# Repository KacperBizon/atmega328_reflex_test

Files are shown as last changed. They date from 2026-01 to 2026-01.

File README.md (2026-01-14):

# reflex test
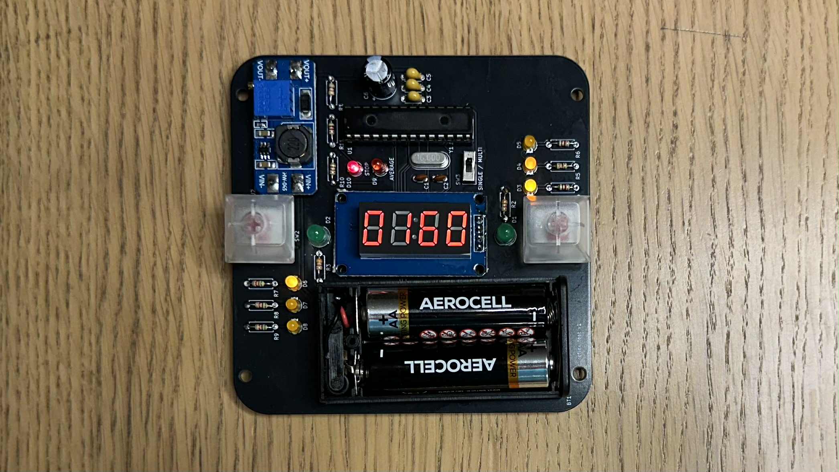
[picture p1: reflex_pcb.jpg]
pcb image


### How to use
- You win by pressing the button on your side faster than your opponent
- To go to the next round press any button for 1s
- Singleplayer - the game finishes with first keypress, multiplayer - both players need to press the keys to finish round 
### Components
- R1 - 10K
- R2-R11 - recommended 3.3k-6.8k
- C1,C2 - 22pF
- C3,C4,C5 - 100nF
- C6 - 10uF

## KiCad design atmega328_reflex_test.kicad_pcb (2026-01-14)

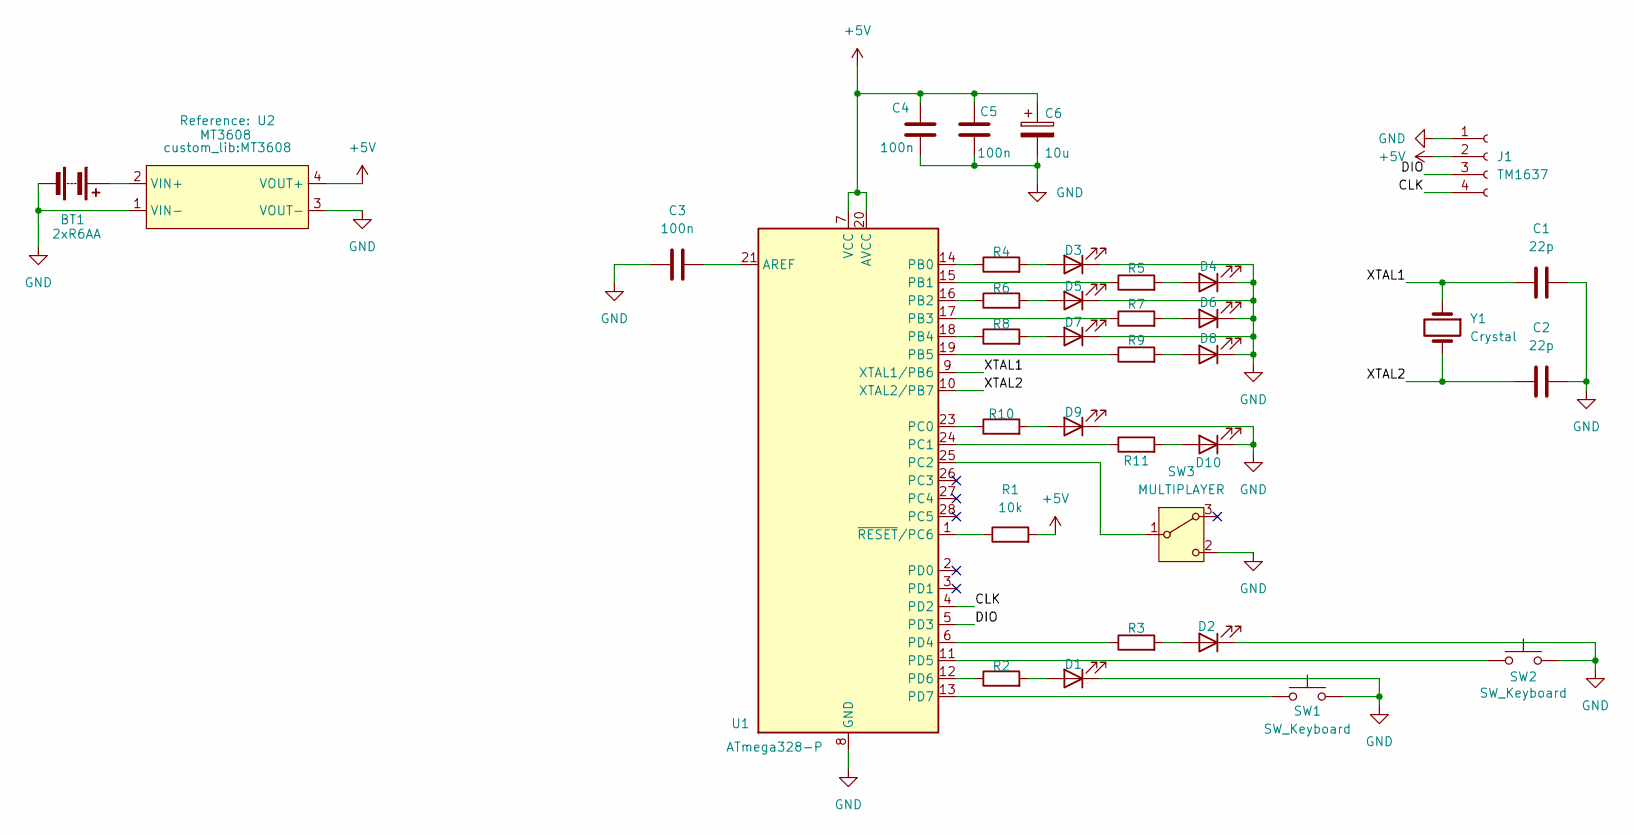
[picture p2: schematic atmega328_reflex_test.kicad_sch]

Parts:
BT1: 2xR6AA; 2xAA_holder
C1, C2: 22p; C_Disc_D3.0mm_W1.6mm_P2.50mm
C3, C4, C5: 100n; C_Disc_D4.3mm_W1.9mm_P5.00mm
C6: 10u; CP_Radial_D8.0mm_P3.80mm
D1, D2: LED; LED_D5.0mm
D3, D4, D5, D6, D7, D8, D9, D10: LED; LED_D3.0mm
J1: TM1637; HW069
R1: 10k; R_Axial_DIN0207_L6.3mm_D2.5mm_P7.62mm_Horizontal
R2, R3: 3k3; R_Axial_DIN0207_L6.3mm_D2.5mm_P7.62mm_Horizontal
R4, R5, R6, R7, R8, R9, R10, R11: 5k1; R_Axial_DIN0207_L6.3mm_D2.5mm_P7.62mm_Horizontal
SW1, SW2: SW_Keyboard; SW_Cherry_MX_1.00u_PCB
SW3: MULTIPLAYER; SW_Slide_8.6x3.8x7.0_P2.54mm
U1: ATmega328-P; DIP-28_W7.62mm
U2: MT3608
Y1: Crystal; Crystal_HC49-4H_Vertical

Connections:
+5V: C4.2, C5.2, C6.1, J1.2, R1.2, U1.7 (VCC), U1.20 (AVCC), U2.4 (VOUT+)
/CLK: J1.4, U1.4 (PD2)
/DIO: J1.3, U1.5 (PD3)
/XTAL1: C1.1, U1.9 (XTAL1/PB6), Y1.1
/XTAL2: C2.1, U1.10 (XTAL2/PB7), Y1.2
GND: BT1.2 (-), C1.2, C2.2, C3.1, C4.1, C5.1, C6.2, D1.1 (K), D2.1 (K), D3.1 (K), D4.1 (K), D5.1 (K), D6.1 (K), D7.1 (K), D8.1 (K), D9.1 (K), D10.1 (K), J1.1, SW1.2, SW2.2, SW3.2 (C), U1.8 (GND), U1.22 (GND), U2.1 (VIN-), U2.3 (VOUT-)
unnamed: BT1.1 (+), U2.2 (VIN+)
unnamed: D1.2 (A), R2.2
unnamed: D2.2 (A), R3.2
unnamed: D3.2 (A), R4.2
unnamed: D4.2 (A), R5.2
unnamed: D5.2 (A), R6.2
unnamed: D6.2 (A), R7.2
unnamed: D7.2 (A), R8.2
unnamed: D8.2 (A), R9.2
unnamed: D9.2 (A), R10.2
unnamed: D10.2 (A), R11.2
unnamed: SW3.1 (B), U1.25 (PC2)
unnamed: C3.2, U1.21 (AREF)
unnamed: R4.1, U1.14 (PB0)
unnamed: R5.1, U1.15 (PB1)
unnamed: R6.1, U1.16 (PB2)
unnamed: R7.1, U1.17 (PB3)
unnamed: R8.1, U1.18 (PB4)
unnamed: R9.1, U1.19 (PB5)
unnamed: R10.1, U1.23 (PC0)
unnamed: R11.1, U1.24 (PC1)
unnamed: R3.1, U1.6 (PD4)
unnamed: SW2.1, U1.11 (PD5)
unnamed: R2.1, U1.12 (PD6)
unnamed: SW1.1, U1.13 (PD7)
unnamed: R1.1, U1.1 (~RESET/PC6)

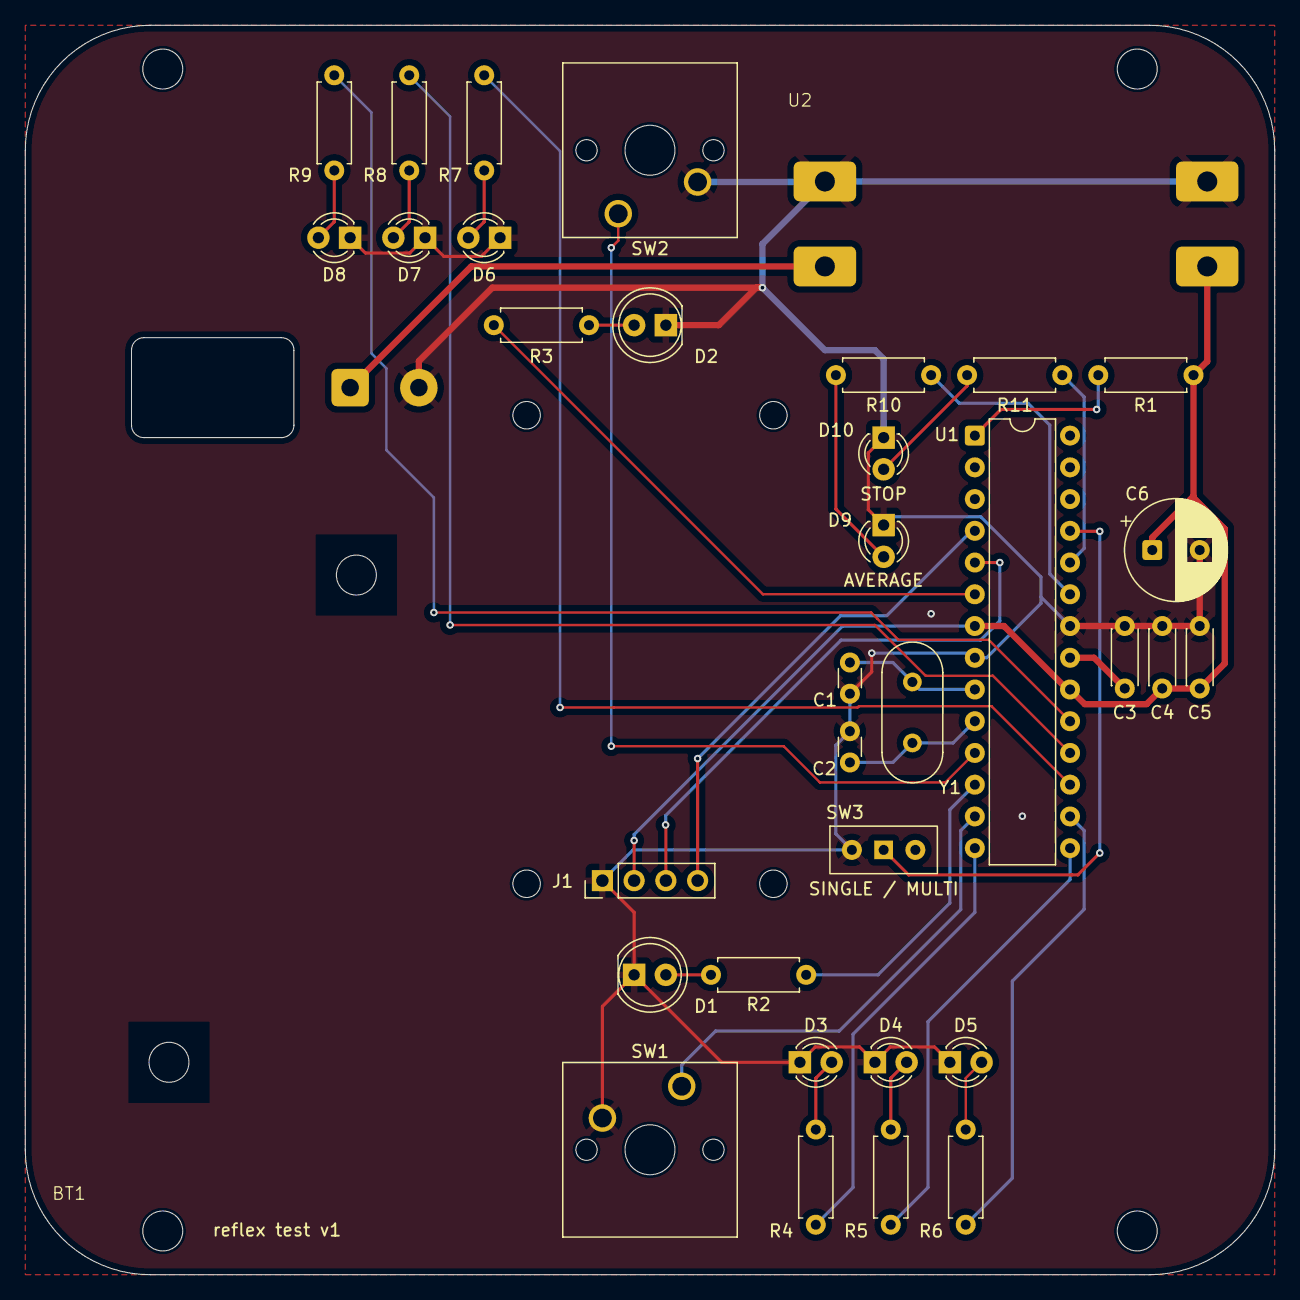
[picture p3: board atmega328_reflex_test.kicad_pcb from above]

Board: 2 copper layers, 100.0 x 100.0 mm, 39 parts (0 on the bottom side), 32 nets.

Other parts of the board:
MH1, MH2, MH3, MH4: MountingHole_3.2mm_M3_DIN965

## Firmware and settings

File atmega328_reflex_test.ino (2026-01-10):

#include <TM1637Display.h>
#include <SPI.h>
#include <SD.h>
#include <math.h>

#define CLK 2
#define DIO 3
TM1637Display display(CLK, DIO);
uint8_t data[] = {0xff, 0xff, 0xff, 0xff};

const byte led_p2 = 4;                    //player 2 main LED
const byte switch_p2 = 5;                 //player 2 switch
const byte led_p1 = 6;                    //player 1 main LED
const byte switch_p1 = 7;                 //player 1 switch

const byte led_score_p1[] = {8, 9, 10};   //player 1 score LEDs
const byte led_score_p2[] = {11, 12, 13}; //player 2 score LEDs

const byte led_avg =  14;                 //avg score LED
const byte led_stop = 15;                 //game stop LED
const byte multiplayer_switch = 16;       //multiplayer if HIGH

const byte MAX_SCORE = 3;
const byte blink_count = 5;               //initial blinks
const int timebetween = 1000;             //time between games

byte multiplayer = 1;
unsigned long p1Total = 0;
unsigned long p2Total = 0;
byte scoreP1 = 0;
byte scoreP2 = 0;

void active_delay(int time)
{
  digitalWrite(led_stop, HIGH);
  while (time)
  {
    if ((digitalRead(switch_p1) == LOW) || (digitalRead(switch_p2) == LOW))
    {
      delay(1);
      time--;
    }
  }
  digitalWrite(led_stop, LOW);
}

void blinkMainLEDs()
{
  for (int i = 0; i < blink_count; i++)
  {
    digitalWrite(led_p1, HIGH);
    digitalWrite(led_p2, HIGH);
    delay(300);

    digitalWrite(led_p1, LOW);
    digitalWrite(led_p2, LOW);
    delay(300);
  }
}

void updateDisplay(unsigned long value, int scoreP1, int scoreP2)
{
  for (int i = 0; i < MAX_SCORE; i++)
  {
    digitalWrite(led_score_p1[i], LOW);
    digitalWrite(led_score_p2[i], LOW);
  }

  for (int i = 0; i < scoreP1; i++)
  {
    digitalWrite(led_score_p1[i], HIGH);
  }

  for (int i = 0; i < scoreP2; i++)
  {
    digitalWrite(led_score_p2[i], HIGH);
  }

  if(value == 0)
  {
    display.clear();
    return;
  }

  value /= 1000;
  
  data[3] = display.encodeDigit(value % 10);
  value /= 10;
  data[2] = display.encodeDigit(value % 10);
  value /= 10;
  data[1] = display.encodeDigit(value % 10);
  value /= 10;
  data[0] = display.encodeDigit(value % 10);

  display.setBrightness(0x01);
  display.setSegments(data);
}

void displayAverage(unsigned long p1Total, unsigned long p2Total, byte scoreP1, byte scoreP2)
{
  digitalWrite(led_avg, HIGH);

  if(multiplayer == 1)
  {
    //p1 average
    if(p1Total > 0)
    {
      digitalWrite(led_p1, HIGH);
      digitalWrite(led_p2, LOW);
      updateDisplay(p1Total/(scoreP1 + scoreP2), scoreP1, scoreP2);

      active_delay(timebetween);
    }

    //p2 average
    if(p2Total > 0)
    {
      digitalWrite(led_p1, LOW);
      digitalWrite(led_p2, HIGH);
      updateDisplay(p2Total/(scoreP1 + scoreP2), scoreP1, scoreP2);

      active_delay(timebetween);
    }
  }
  else //singleplayer
  {
    //p1 average
    if(p1Total > 0)
    {
      digitalWrite(led_p1, HIGH);
      digitalWrite(led_p2, LOW);
      updateDisplay(p1Total/(scoreP1), scoreP1, scoreP2);

      active_delay(timebetween);
    }

    //p2 average
    if(p2Total > 0)
    {
      digitalWrite(led_p1, LOW);
      digitalWrite(led_p2, HIGH);
      updateDisplay(p2Total/(scoreP2), scoreP1, scoreP2);

      active_delay(timebetween);
    }
  }

  digitalWrite(led_avg, LOW);
}

bool falseStart()
{
  unsigned long waitTime = random(3200, 7600) * 1000UL;
  unsigned long safeZone = 1000000UL;
  unsigned long startTime = micros();

  while (micros() - startTime < waitTime)
  {
    if (micros() - startTime > safeZone)
    {
      if ((digitalRead(switch_p1) == LOW) || (digitalRead(switch_p2) == LOW))
      {
        data[3] = display.encodeDigit(15);
        data[2] = display.encodeDigit(15);
        data[1] = display.encodeDigit(15);
        data[0] = display.encodeDigit(15);
        display.setBrightness(0x01);
        display.setSegments(data);

        digitalWrite(led_stop, HIGH);

        active_delay(timebetween);
        return 1;
      }
    }
  }

  return 0;
}

void reflexTest()
{
  bool finished_players[2]={0, 0};
  digitalWrite(led_p1, HIGH);
  digitalWrite(led_p2, HIGH);

  unsigned long startTime = micros();
  unsigned long reactionTime = 0;

  while(finished_players[0] == 0 || finished_players[1] == 0)
  {
    //calculate time after falsestart()
    reactionTime = micros() - startTime;

    //player 1
    if (digitalRead(switch_p1) == LOW && finished_players[0] == 0)
    {
      if(finished_players[1] == 0)
      {
        digitalWrite(led_p1, HIGH);
        digitalWrite(led_p2, LOW);
        scoreP1++;
        updateDisplay(reactionTime, scoreP1, scoreP2);
      }

      p1Total += reactionTime;
      finished_players[0] = 1;

      if(multiplayer == 0)
        return;
    }

    //player 2
    if (digitalRead(switch_p2) == LOW && finished_players[1] == 0)
    {
      if(finished_players[0] == 0)
      {
        digitalWrite(led_p1, LOW);
        digitalWrite(led_p2, HIGH);
        scoreP2++;
        updateDisplay(reactionTime, scoreP1, scoreP2);
      }

      p2Total += reactionTime;
      finished_players[1] = 1;

      if(multiplayer == 0)
        return;
    }

    if (reactionTime > 9990000)
    {
      digitalWrite(led_p1, LOW);
      digitalWrite(led_p2, LOW);

      //both players didnt finish - doesnt count 
      if((finished_players[0] == 0) && (finished_players[1] == 0))
      {
        updateDisplay(9999000, scoreP1, scoreP2);
        return;
      }

      if(finished_players[0] == 0)
        p1Total += reactionTime;

      if(finished_players[1] == 0)
        p2Total += reactionTime;

      return;
    }
  }
}

void handleGame()
{
  display.clear();
  digitalWrite(led_p1, LOW);
  digitalWrite(led_p2, LOW);

  if (falseStart() == 0)
    reflexTest();

  active_delay(timebetween);
}

void setup() 
{
  randomSeed(analogRead(3));

  pinMode(switch_p1, INPUT_PULLUP);
  pinMode(switch_p2, INPUT_PULLUP);

  pinMode(led_p1, OUTPUT);
  pinMode(led_p2, OUTPUT);

  for (int i = 0; i < MAX_SCORE; i++) 
  {
    pinMode(led_score_p1[i], OUTPUT);
    pinMode(led_score_p2[i], OUTPUT);
  }

  pinMode(led_avg, OUTPUT);
  pinMode(led_stop, OUTPUT);
  pinMode(multiplayer_switch, INPUT_PULLUP);

  blinkMainLEDs();
}

void loop()
{
  p1Total = 0;
  p2Total = 0;
  scoreP1 = 0;
  scoreP2 = 0;
  updateDisplay(0, scoreP1, scoreP2);

  multiplayer = digitalRead(multiplayer_switch);

  while(scoreP1 < MAX_SCORE && scoreP2 < MAX_SCORE)
  {
    handleGame();
  }

  displayAverage(p1Total, p2Total, scoreP1, scoreP2);
}

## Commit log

2025-11-11 empty nano
    [NanoV3.3.kicad_sch]
2025-11-13 atmega328p minimal
    [NanoV3.3.kicad_sch, atmega328_reflex_test.kicad_pcb, atmega328_reflex_test.kicad_sch]
2025-11-13 update files
    [atmega328_reflex_test.kicad_pcb, atmega328_reflex_test.kicad_sch]
2025-11-16 shematic without power supply
    [atmega328_reflex_test.kicad_sch]
2025-11-26 add custom footprints
2025-11-29 added power supply
    [atmega328_reflex_test.kicad_sch]
2025-12-05 finish schematic and general layout
    [atmega328_reflex_test.kicad_pcb, atmega328_reflex_test.kicad_sch]
2025-12-14 pcb components laid out
    [atmega328_reflex_test.kicad_pcb]
2025-12-14 initial wiring
    changed pin 4 with pin 7
    [atmega328_reflex_test.kicad_pcb, atmega328_reflex_test.kicad_sch]
2025-12-15 version 1 finished
    [atmega328_reflex_test.kicad_pcb, atmega328_reflex_test.kicad_sch]
2026-01-14 update resistor values
    [atmega328_reflex_test.kicad_pcb, atmega328_reflex_test.kicad_sch]
